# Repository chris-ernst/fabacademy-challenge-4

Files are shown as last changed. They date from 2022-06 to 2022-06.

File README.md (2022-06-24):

# Hybrid Ecosystems

## Building a bio-based MIDI controller for an interactive audiovisual performance

# SCOPE
Tati, Joaco and Chris are building a bio-based A/V interface. 

Basic structure:

1. Inputs (buttons) 
2. PCB
3. Outputs (Audio & Visuals)

In this documentation we will focus on the fabrication of the controller and the electronics as this was the main focus this week, but we will also touch upon wireless communication protocols. 

## [See our progress summary video on Vimeo](https://vimeo.com/717057704)

- [x] Initial idea / Concept of the Project ( What questions need to be answered?)

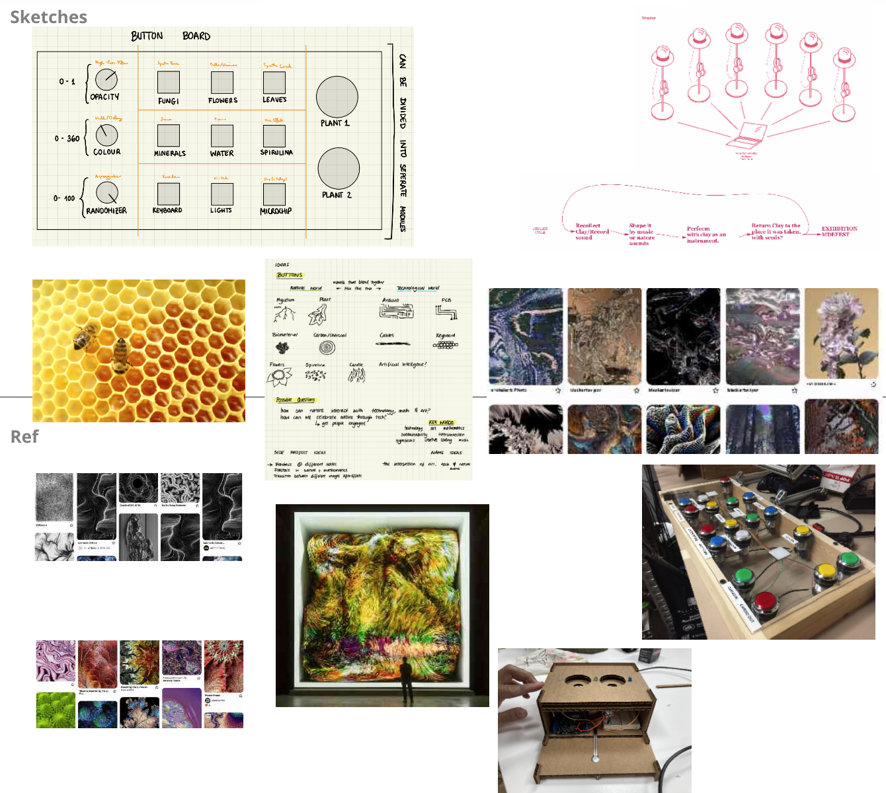
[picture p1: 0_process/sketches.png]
 

_How can we rethink a musical instrument? What are inputs, and how can they change shape and colors? How can we create engaging, collborative interactions with a button board?_

We wanted to make a modular button input system. After initially thinking about producing some sort of playable MIDI keyboard, we thought it could be interesting to incorporate two of Akasha hub's values into the design: decentralisation & sustainable relationships. So we designed the possibility for distributed buttons (which could be placed together with magnets or farther away) and rethought the buttons' materiality by using biomaterials.

We were inspired by the structure a visual aspect of beehives, which is why we ended up going for the hexagonic shape.

For the challenge we wanted to test out a diversity of inputs: we selected a "normal" clicking button, a potentiometer and a pressure sensor. This way, we could get a good understanding of each one and simply scale up the process based on our needs in the future.

- [x] Purpose: What is it supposed to do?

These buttons would then trigger visuals through Touchdesigner and audio through Ableton, at the same time, through TDAbleton protocols using wireless communication through IP addresses.

# ACADEMIC LEVEL

## Long term dissemination plan
explain the strategy you will use to share with future users your project (licences, tools, communication, etc)

Easy to scale up: we already have the 3D files for a button, potentiometer and pressure sensor, so it is only a matter of repeating the 3D printing.

As for the audiovisual files, Touchdesigner is free for personal use and has a very active community, so we could post the file on TD forums for people to use and learn. Ableton, on the other hand is very not open source and expensive, so it wouldn't be easy to share that with people who do not have a license for it.

- [x] Explain how it's linked to your research areas

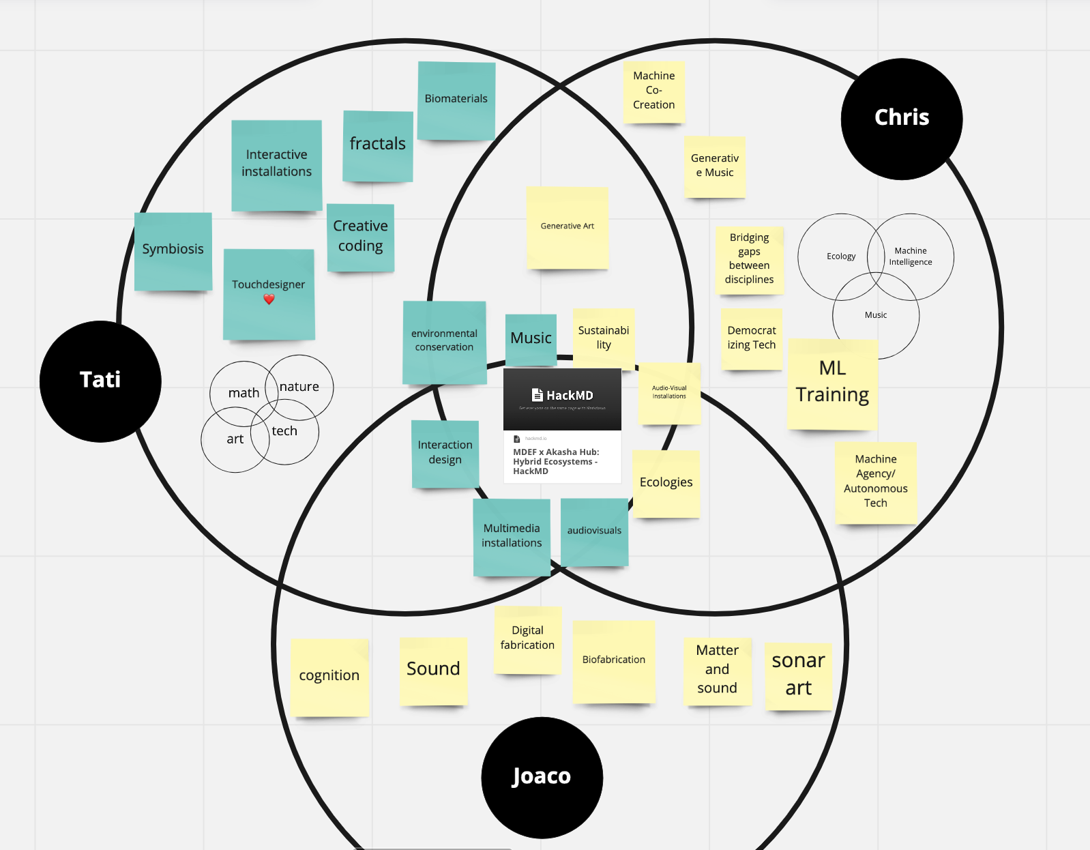
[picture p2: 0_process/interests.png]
 

Our research areas are very similar, even though we hav different focal points. The common areas are music, sustainability, environmental awareness, multimedia installations, interaction design, ecologies and audiovisuals. Our individual niches and specialties are 
  - Juaco: sound, digital fabrication, matter & sound, sonar art, biofabrication and cognition
  - Tatiana: interactive installations, creative coding, symbiotic relationships, fractals, biomaterials and the one and only Touchdesigner <3
  - Chris: ML training, Autonomous tech, democratising tech, bridging gaps between disciplines, generative music.

We've liked working together because we manage to each find a way to reach a common objective (Audiovisual VJ set with biomaterials) without compromising our specific interests (bio fabrication, creative coding, generative music etc.).

- [x] Show how your team planned and executed the project

We divided the group based on skills and interests: Juaco worked on the 3D printing, moulding & casting and soldering, Chris worked on the electronics, pcb milling and Ableton sountrack and Tatiana figured out how to structure the pipeline in Touchdesigner to receive, remap and send data through various protocols.
We often teamed up and helped each other out on various tasks but generally, we can say that our biggest tasks were digital fabrication, biomaterial moulding, PCB milling, electronics, wireless communications, audio & visuals generation.

- [x] System diagram (illustration explaining function, parts, and relations)

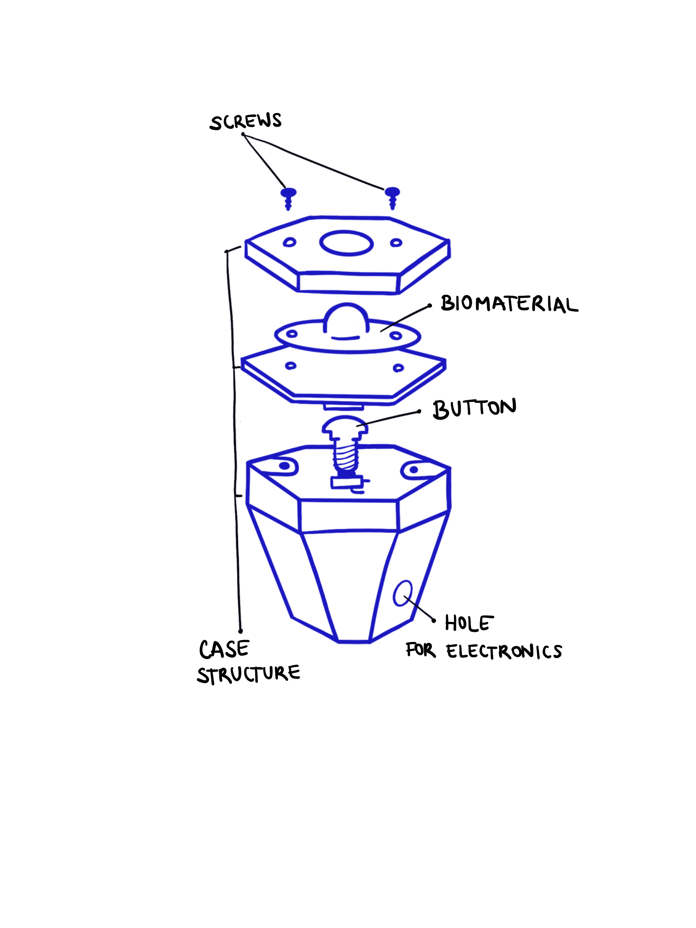
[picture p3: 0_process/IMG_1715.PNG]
 
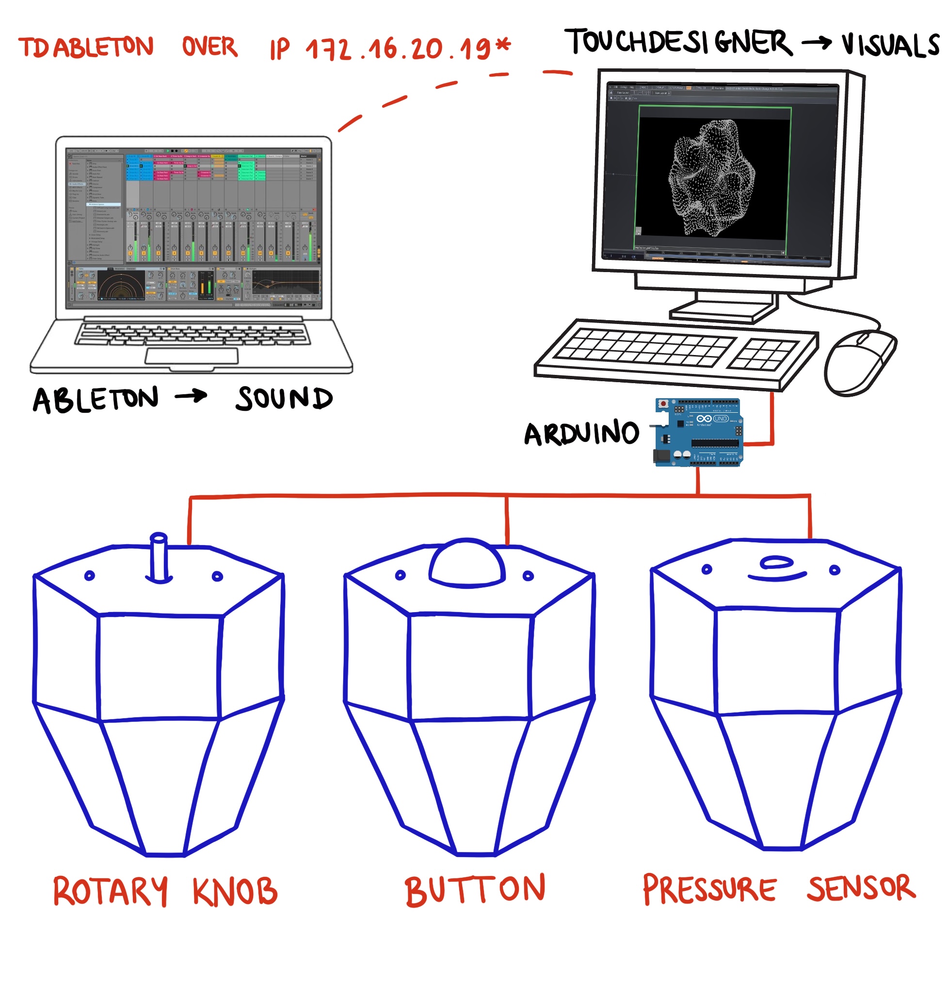
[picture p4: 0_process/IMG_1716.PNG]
 

All the buttons are connected to Arduino that is communicating the data to Touchdesigner. Each button triggers a visual + sound and each potentiomenter changes the color, shape and pitch.

- [x] BOM (Build of Materials)

Material used:

- 3 buttons
- 3 potentiometers
- 1 touch sensor
- biomaterials
- 3D materials for printing models for moulding and casting
- 3D materials for printing the box
- cables
- screws
- Arduino board

## Button board

This button board requires 3D modelling, molding and casting, electronics.

- [x] Integrated Design (How you designed it - relation between elements)

The input (button, rotor, pressure sensor) has a 3D printed case which keeps it stable and allows us to place it where we want. It is connected to the arduino (Code found in project files) which communicates the data into touchdesigner. This data is either binary, 0/1 for the button, or a range, like 0-1023 for the rotary knob. This data is remapped in Touchdesigner according to our needs: for example, 0-1023 is remapped to 1-360 in order for the rotary knob to change the hue of the colour selected in the visual. The buttons activate the visuals in Touchdesigner, but also simulatenously send midi values to ableton thanks to the TDAbleton link we set up for the two softwares to communicate.

- [x] Honest Design (use of technology in a meaningful way) Relation to the topics

We believe the technology was used in a meaningful way because we thought about how to conceptually match our vision with the experience. In other words, since we want participants to think about how technology, art and nature are connected in a collaborative way, we wanted this to be reflected in the button board itself, which is why we chose to make it decentralised with biomaterial and electronic components.

- [x] Be creative (find solutions with materials and technology you have)

We were creative in our approach and execution of the product, starting from the sketches, to the cardboard prototype and finally the product itself.

- [x] Explore design boundaries (based on your expertise)

We were unfamiliar with OSC and IP communication protocols, so this was an area we really had to push ourselves in, but it ended up being very beneficial.

- [x] Listed future development opportunity for this project

We want to scale up this project to 9 buttons, 3 rotary knobs and even plants, so that we can have a big, multi-person, interactive jamming board.

# REPLICABILITY

- [x] How did you fabricate it (fabrication processes and materials)

All of the files are inside the folder.

Juaco started out by prototyping the button cases in cardboard, and surely enough he whipped up a great prototype out of nowhere.

### 3D Fabrication

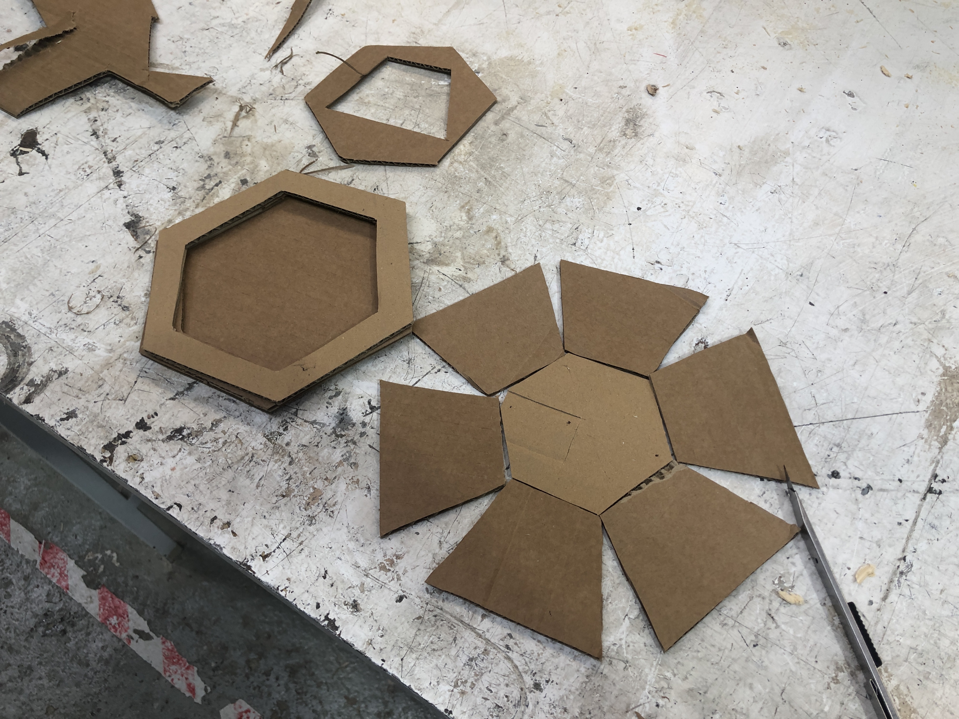
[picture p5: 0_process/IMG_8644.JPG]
 
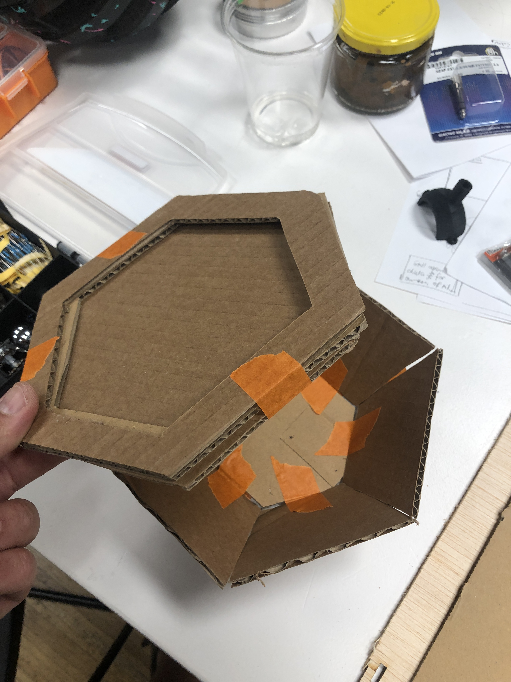
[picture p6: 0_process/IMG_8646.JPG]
 

Then, he designed the final structure to be 3D printed in Fusion 360, with slight tweaks for each type of input (based on the shape of the button/knob).

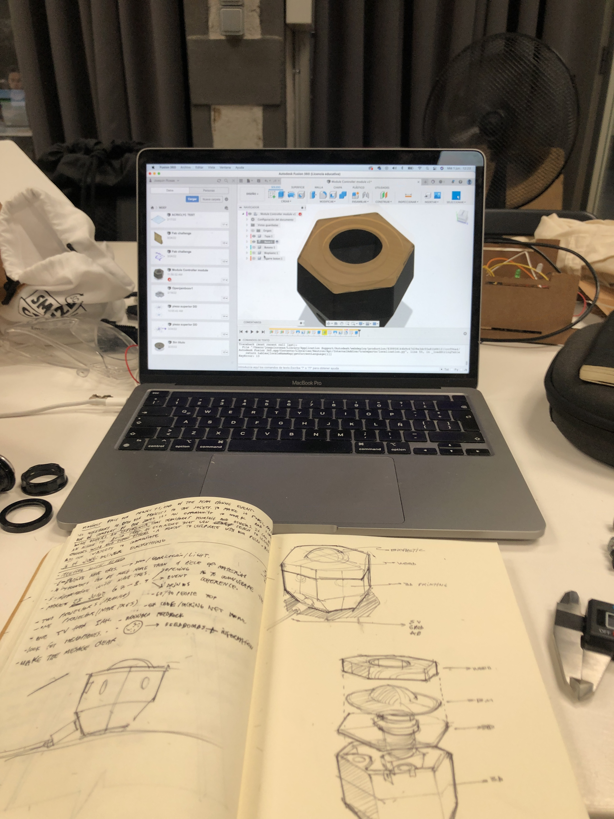
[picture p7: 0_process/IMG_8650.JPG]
 
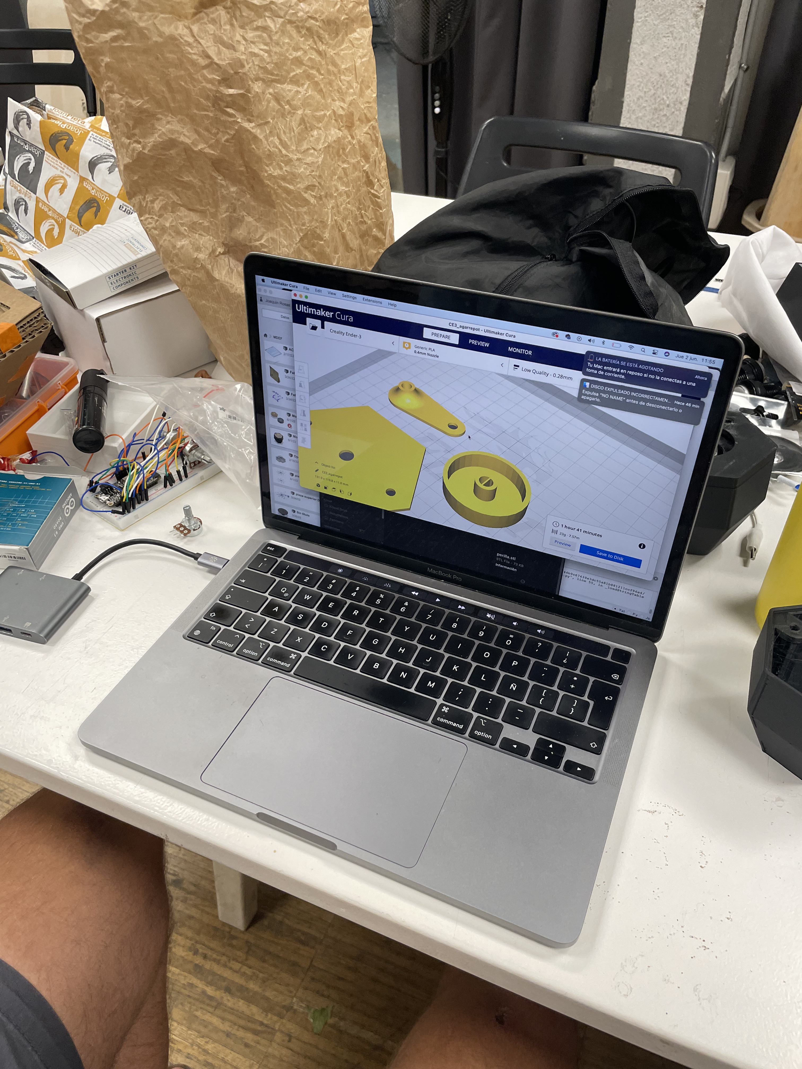
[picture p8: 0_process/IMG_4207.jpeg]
 

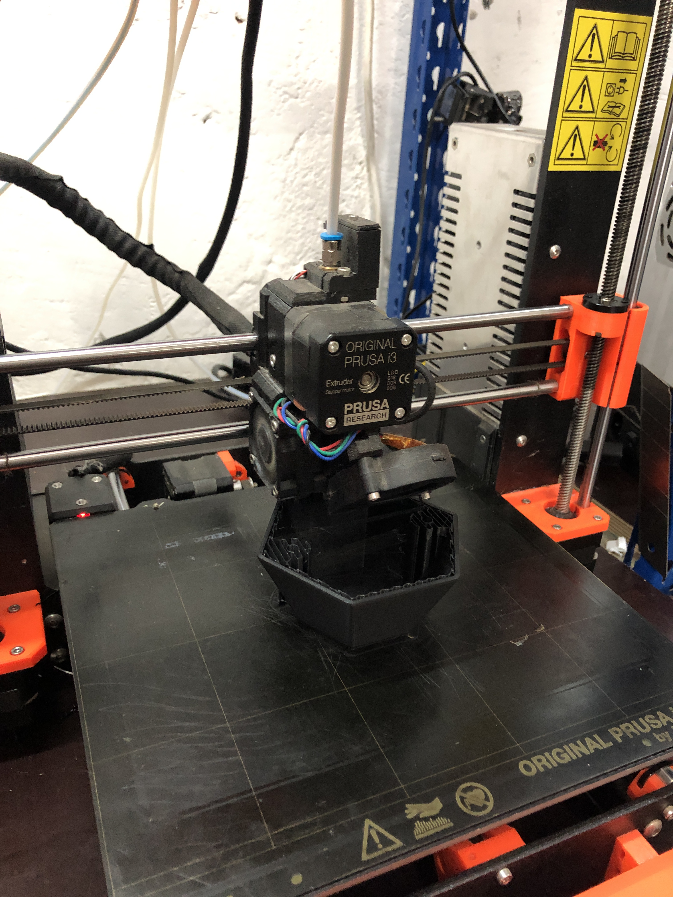
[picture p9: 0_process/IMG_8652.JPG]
 
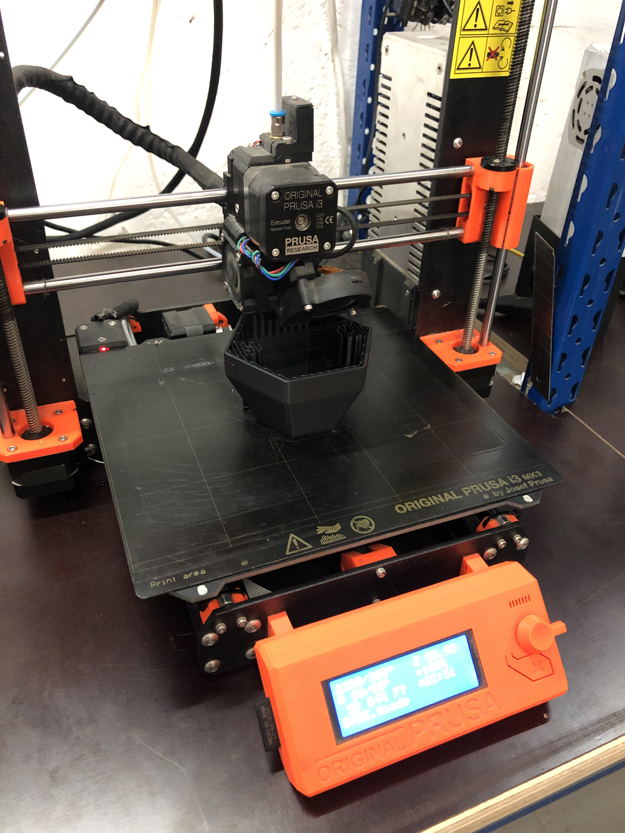
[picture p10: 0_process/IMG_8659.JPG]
 

### Molding & Casting

Recipe for biomaterials can be found [here](/2_biomaterials).

Juaco also designed the mould for the biomaterials, so that it could fit perfectly into the case.

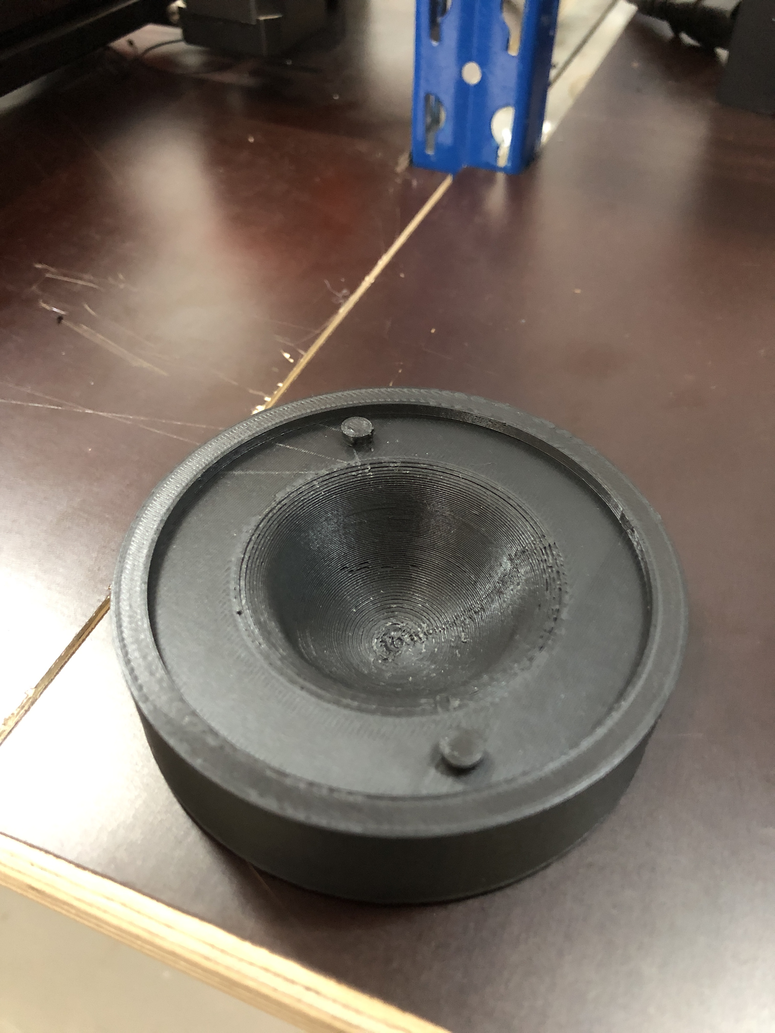
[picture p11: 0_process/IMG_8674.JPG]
 
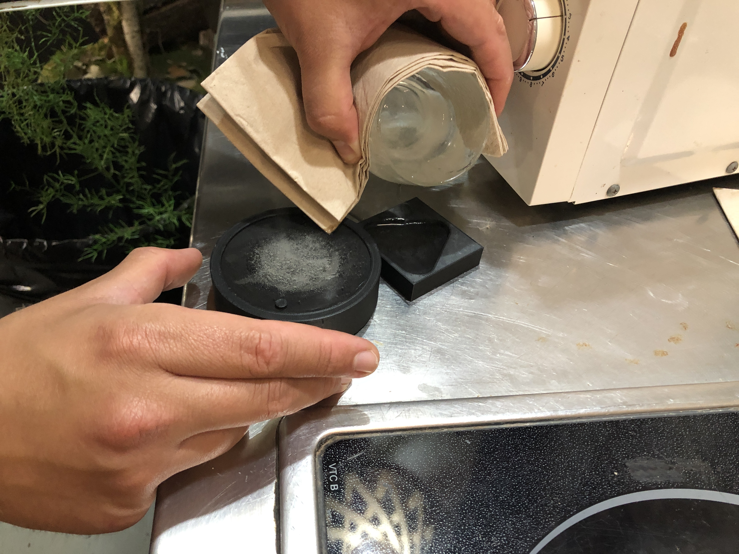
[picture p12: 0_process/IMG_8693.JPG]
 
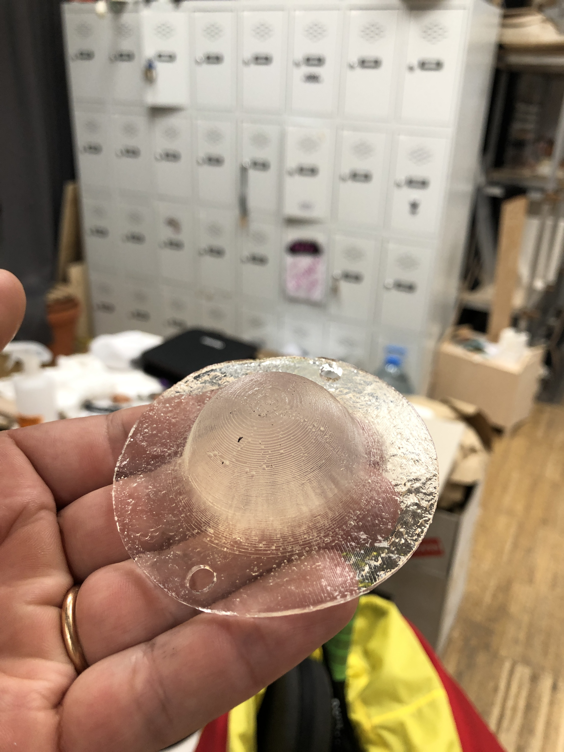
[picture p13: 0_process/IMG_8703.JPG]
 

### Milling and Soldering an Arduino Shield

Chris was responsible for designing, milling and soldering a Arduino Shield to multiply the GND and 5V outputs for the controller. 

Some notes on fabrication
- Trace mill: min. 1/64"
- Outline mill: 1/32"
- Trace seperation: 2.55mm
- Minimal trace width: 0.35mm 
- Trace clearance: 0.4mm
- Hole diameter: 1mm

PCB files can be found [here](/1_fabrication/Arduino_Shield).

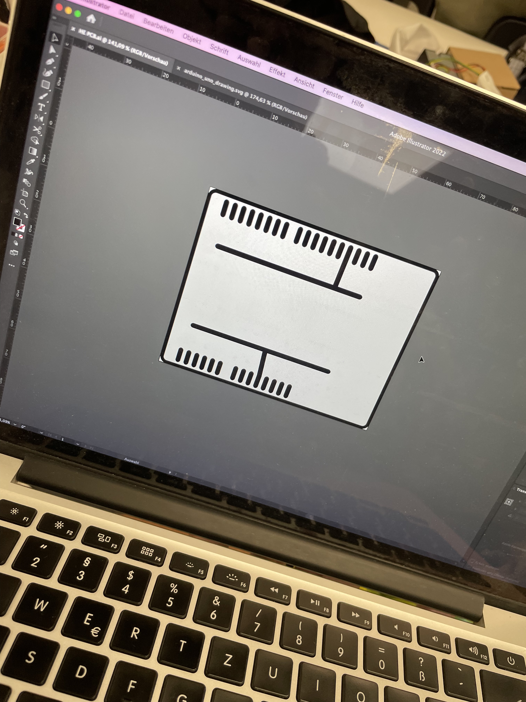
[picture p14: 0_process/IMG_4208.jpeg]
 
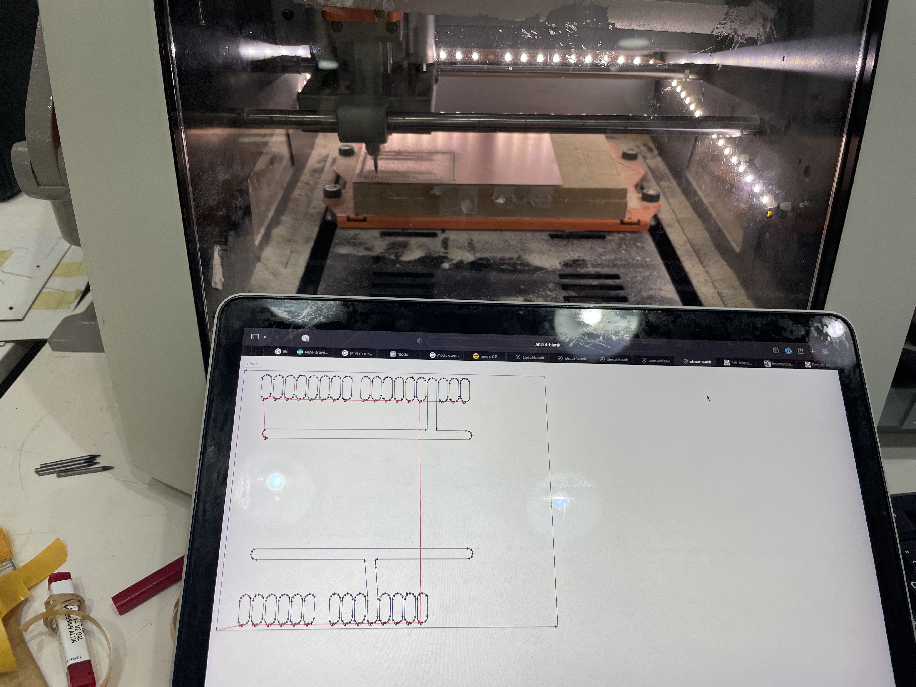
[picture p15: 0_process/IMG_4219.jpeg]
 
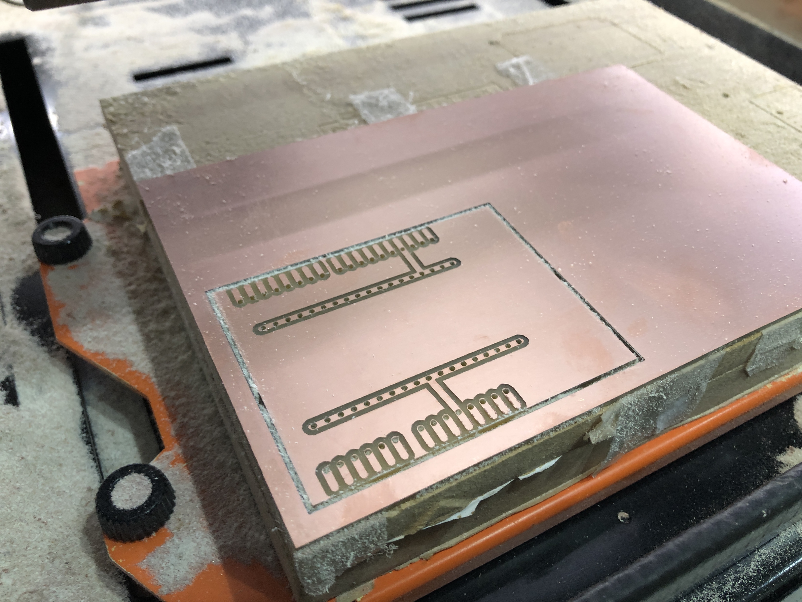
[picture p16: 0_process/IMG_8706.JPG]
 
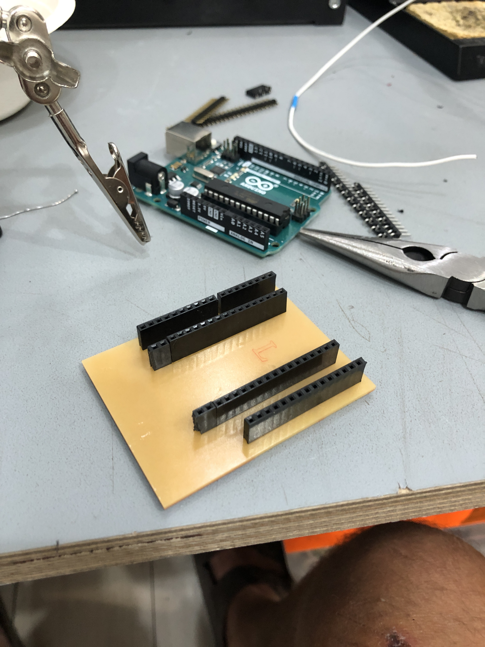
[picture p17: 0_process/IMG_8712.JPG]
 
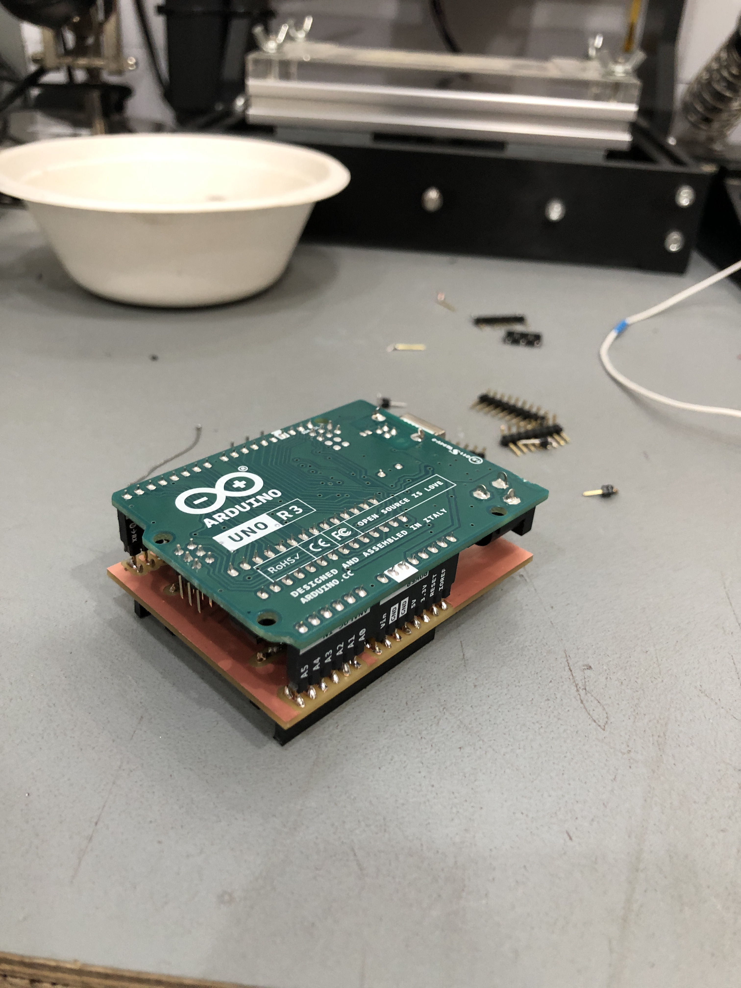
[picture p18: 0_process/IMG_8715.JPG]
 

## Audiovisuals

Tatiana coordinated the audiovisuals and managed the incoming and outgoing data

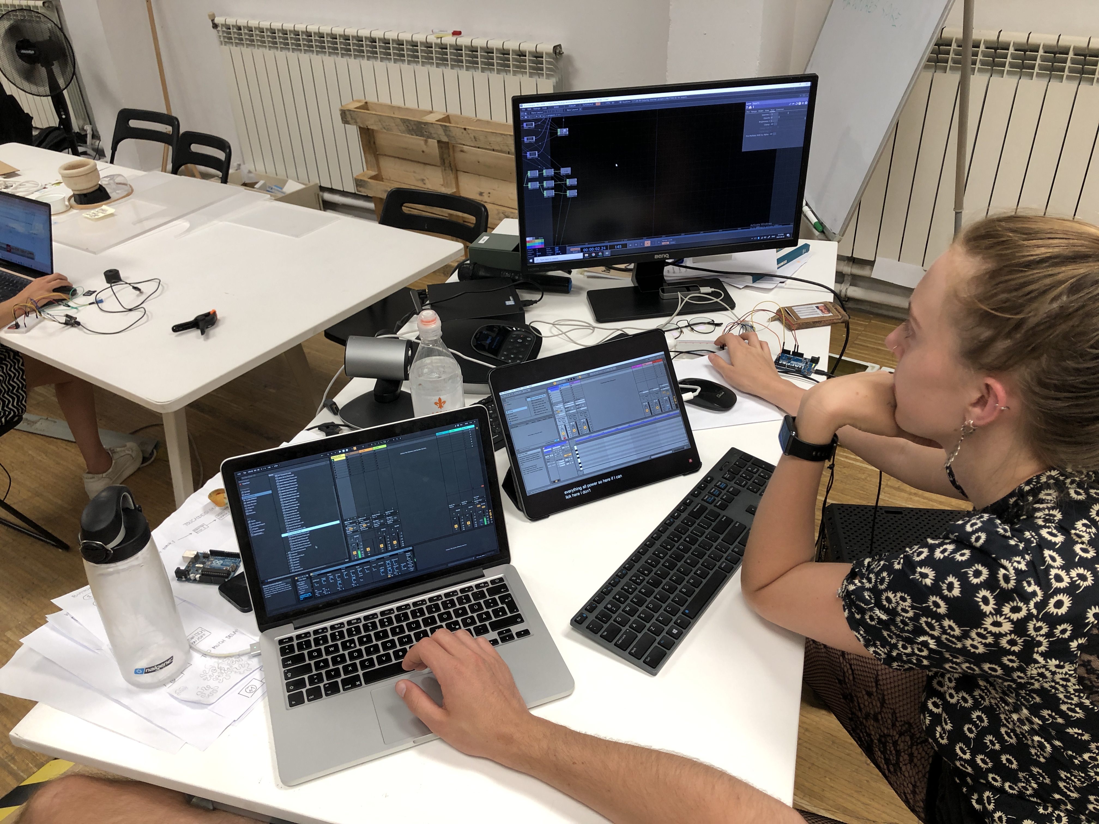
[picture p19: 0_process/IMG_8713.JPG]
 
 

Together, we worked on the electronics, iterating based on our testing needs. We started out with a simple button and then proceeded to add knobs and pressure sensors. Chris and Tatiana worked on the arduino code and how to visualise it in Touchdesigner.

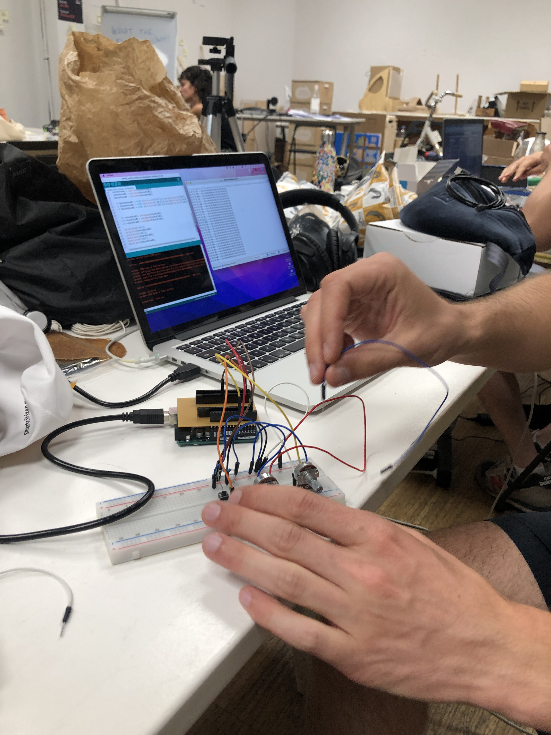
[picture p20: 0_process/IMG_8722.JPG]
 

- [x] Iteration Process (spiral development)

For the input cases

Cardboard prototype -> breadboard electronics -> 3D printed casing -> button biomaterial moulding 

For the audiovisual pipeline

1. Understanding OSC protocols with TouchOSC app communicating with Touchdesigner (just to get familiar with IP addresses and ports)
2. Receiving data from Arduino by using Serial DAT (operator node which receives serial data)
3. Communicating interchangeably between Touchdeisgner and Ableton, using TDAbleton over IP address

In both cases, we scaled up the difficulty over time, once we understood the basics of the software or technique.

- [x] Described problems and how the team solved them

As always, we had many bugs in the code, within the protocols and we often had to 

Out of all challenges, however, this was the one where we faced the least difficulties because we were so prepared and determined to getting things done, but also because we distributed our skills well and evenly without experimenting too much. It's always important to balance the experimenting enough to be out-of-the-box, yet be rigorous with time and organisation in order to finish within the deadlines.

- [x] Photographies of the end artifacts

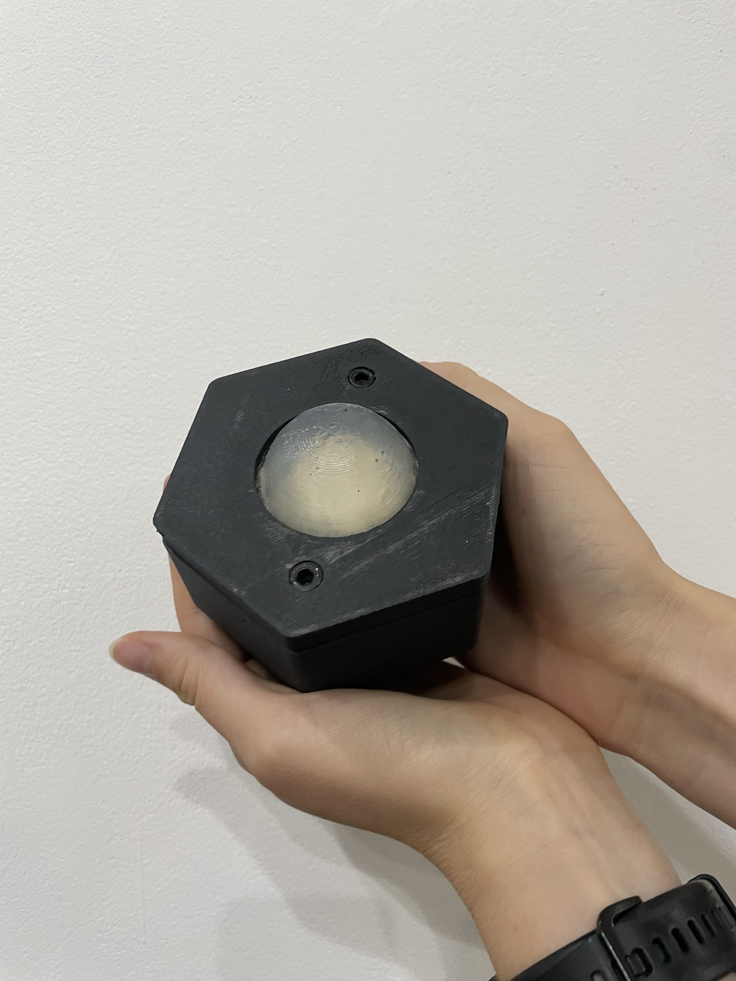
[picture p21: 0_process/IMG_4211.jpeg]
 

You can find the final process video [here](https://vimeo.com/717057704)

- [x] Dealing with uncertainty + Don't be afraid to make mistakes

The IAAC wifi sucks. Especially when there are dozens of students git pushing and uploading last minute files onto the repo. We were actually really disappointed with our final presentation because we were looking forward to showcasing our week of hard work to the class and professors, but the wifi bandwidth was not stable enough to maintain a connection between Tatiana and Chris' computer, which meant that Touchdesigner and Ableton were not able to communicate.

This is something to keep in mind for the final show, but maybe it was a way of us not "spoiling" the magic of the event.

## UPDATES !! <3

- [x] Explore design boundaries (based on your expertice)

We were unfamiliar with OSC and IP communication protocols, so this was an area we really had to push ourselves in, but it ended up being very beneficial to us. By doing this, we could then make Tatiana + Chris' computers communicate wirelessly, using two totally different programs through the magic powers of WIFI.

In addition to this, we believe our design was unique due to its modular button system. After initially thinking about producing some sort of playable MIDI keyboard in the shape of a box or drum pad, we thought it could be more interesting to make the components detachable and independant.

Juaco and Chris had explored making a loop station in the past, so choosing to sticking to that type of instrument would have been repetitive and solvable by already existing products (VJ button board, drum kits, keyboards...). However, by making the buttons in seperate components, we make our output unique and each show could be different. For example, we could have one show with the buttons all together in a beehive shape, and another where they are far apart. 

The distributed buttons' materiality is also innovative because of the use of biomaterials rather than silicone or plastic. This adds an interesting tactility when playing the buttons which is unlike other instruments. We would like to play around with the biomaterial textures and colours in the future.

- [x] Long term dissemination plan

The FabChallenge was a way for us to test out the technical side of our final exhibition. After coming up with the idea to have a DJ set at Akasha hub with various buttons to trigger the visuals, we wanted to make this possible with the skills we acquired over the course of  Fabacademy. The challenge allowed us to test various button possibilities and see which one was most suitable to be scaled up at the Akasha event, but also future events. 

We believe that the parametric design makes it easy to scale up: we already have the 3D files for our key elements, the button, potentiometer and pressure sensor, so it is only a matter of repeating the 3D printing to scale up the equipment. If we want to make slight modifications to the design it would be possible too, changing the parametric attributes on Fusion.

As for the audiovisual files, Touchdesigner is free for personal use and has a very active community, so we could post the file on TD forums for people to use and learn. Ableton, on the other hand is very not open source and expensive, so it wouldn't be easy to share that with people who do not have a license for it. This is what regards the dissemination of the project files.

When it comes to scaling up the actual experience beyond MDEF and Akasha hub, we have been discussing a few ideas. We think it would be very interesting to submit the project to certain design festivals, such as ARS Electronica or the Dutch Design week. This will all depend on the outcome of the Akasha event, and whether it is a success or not. If this would happen and we needed more artifacts, it would be easier to scale up for the reasons mentioned before: 3D printing the structure and replicating it. 

Ultimately, this is why we chose having a distributed button system, rather than a simple board. If we had a board, it wouldn't have been as flexible as the various buttons which can be produced and added on demand.

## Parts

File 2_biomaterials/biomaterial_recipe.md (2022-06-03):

# Biomaterial Recipe:

Agar Agar :4g

Water: 80 ml

Glycerin: 15 ml

Process: Mix everything togueter while its cold, then pour the mix on a glass, and heat it in a microwave for 1.30 min.

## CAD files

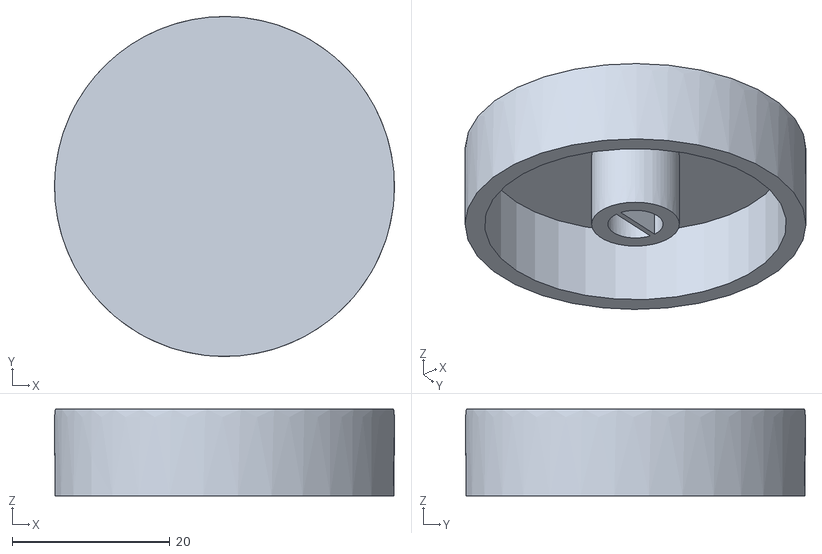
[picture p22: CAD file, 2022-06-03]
1_fabrication/STL files/perilla.stl
43.1 x 43.1 x 11.0

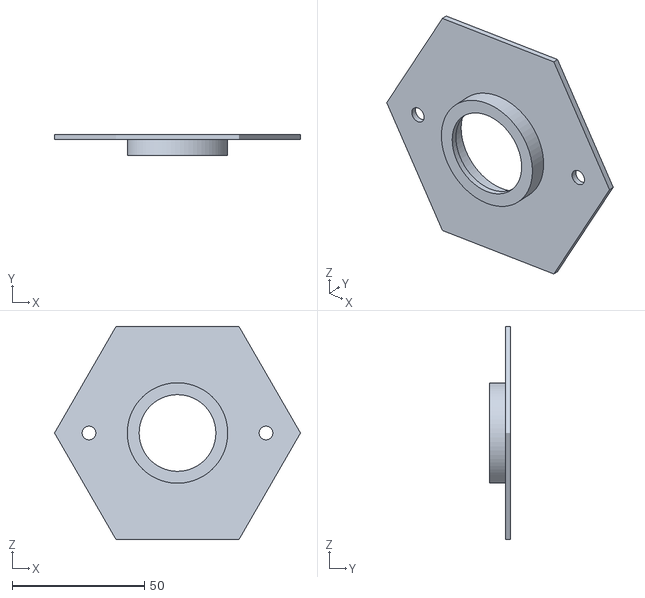
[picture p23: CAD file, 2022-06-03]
1_fabrication/STL files/button holder.stl
93.1 x 8.00 x 80.6

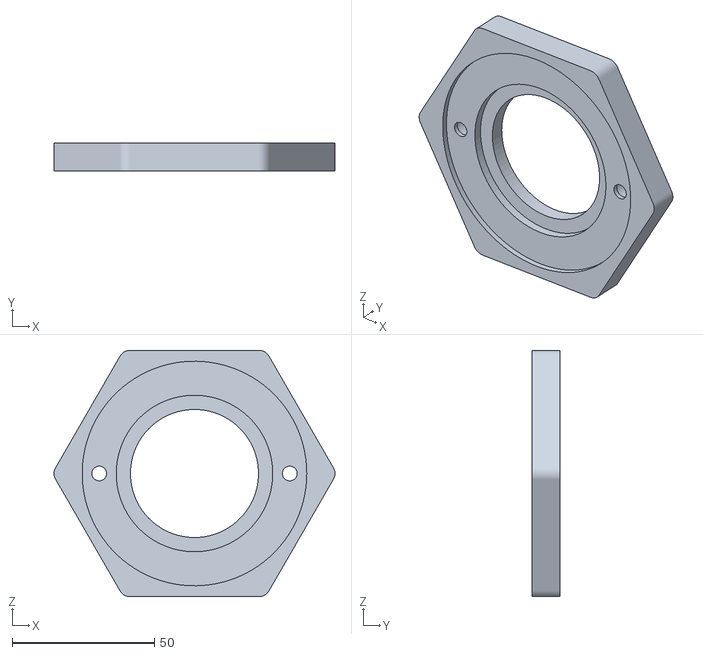
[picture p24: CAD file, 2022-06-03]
1_fabrication/STL files/button lid.stl
98.8 x 10.0 x 86.6

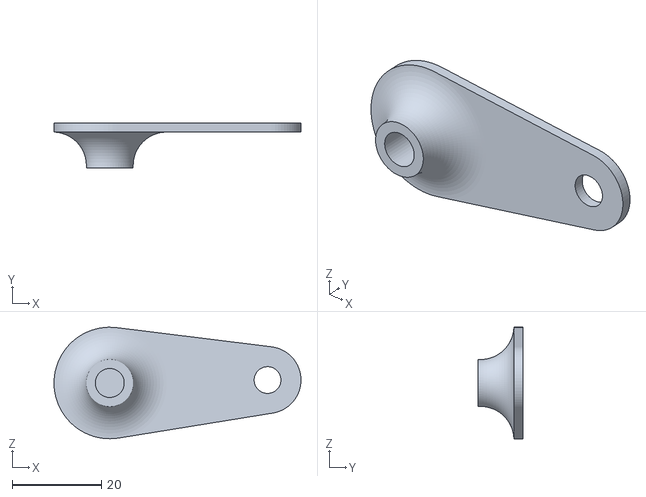
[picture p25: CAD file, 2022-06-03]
1_fabrication/STL files/lever.stl
55.3 x 10.0 x 25.0

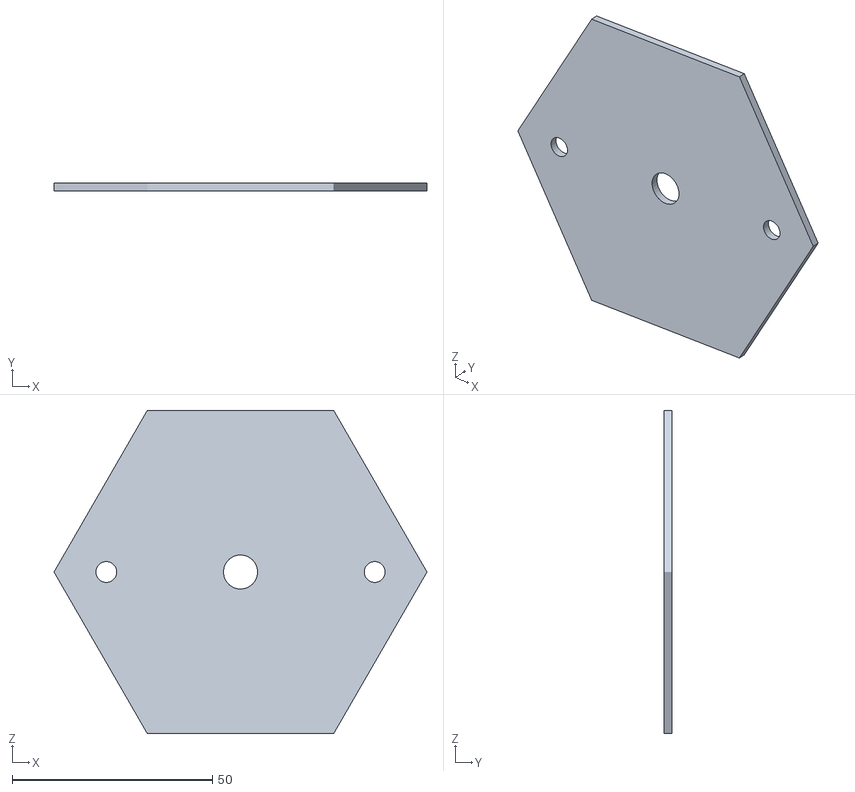
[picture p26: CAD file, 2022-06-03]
1_fabrication/STL files/Potentiometer holder.stl
93.1 x 2.00 x 80.6

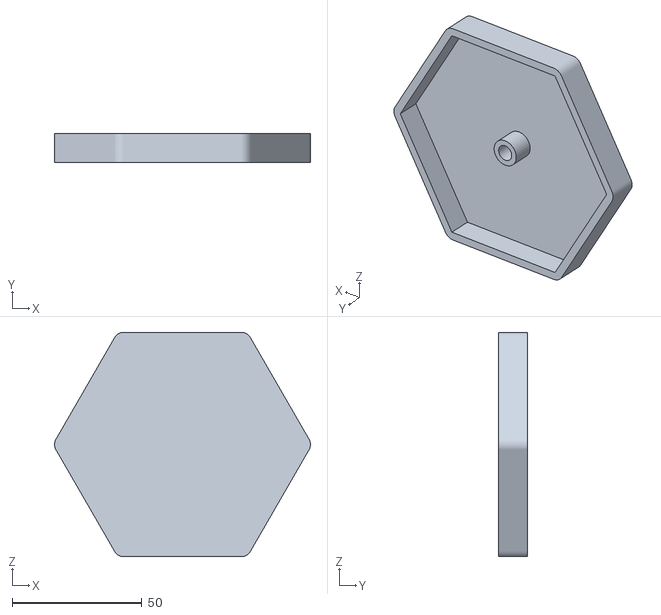
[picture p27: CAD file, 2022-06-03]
1_fabrication/STL files/pot lid.stl
98.8 x 11.0 x 86.6

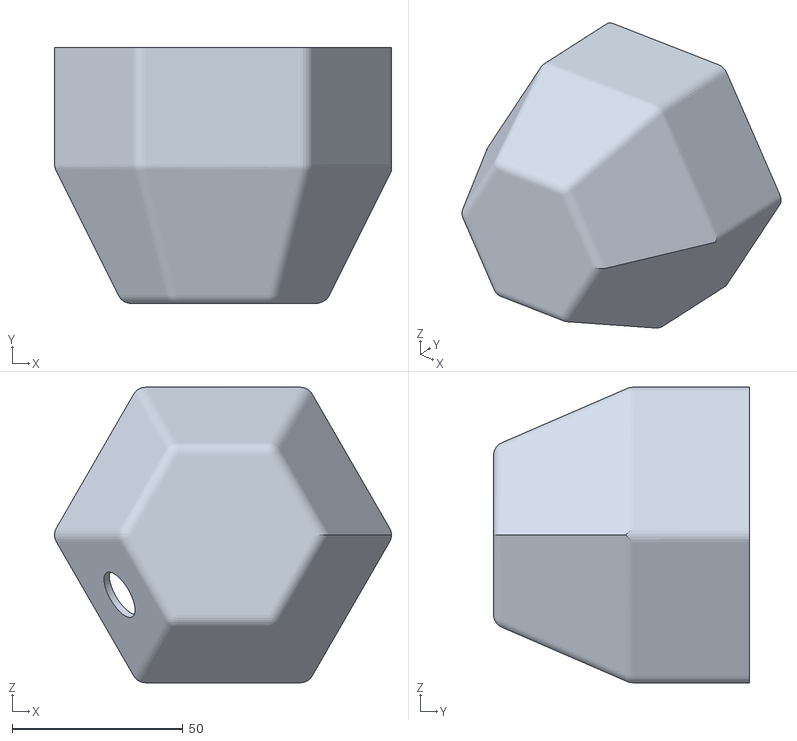
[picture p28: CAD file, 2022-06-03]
1_fabrication/STL files/BASE.stl
98.7 x 75.0 x 86.6

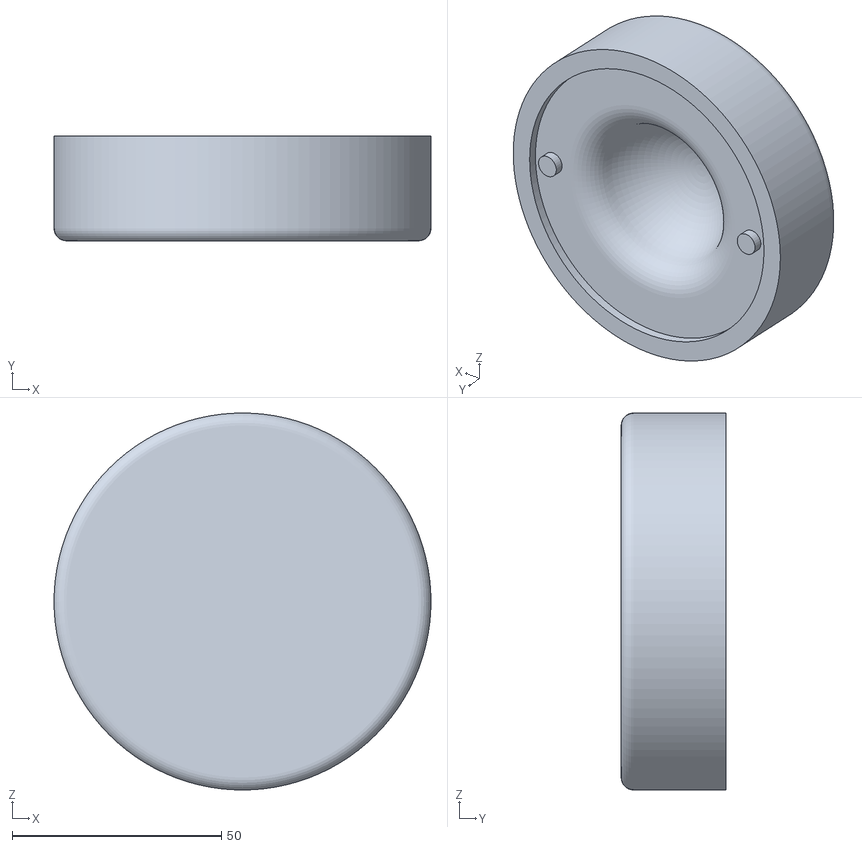
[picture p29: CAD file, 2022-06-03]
1_fabrication/STL files/mold.stl
90.0 x 25.0 x 90.0

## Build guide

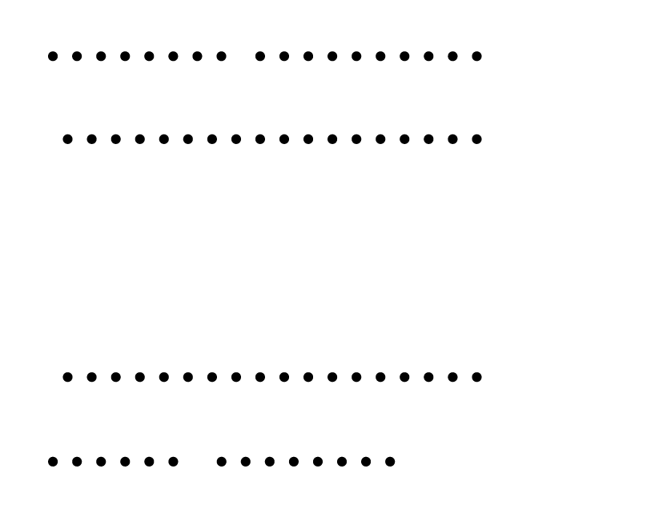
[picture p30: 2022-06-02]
1_fabrication/Arduino_Shield/PNG Files/HE PCB_holes.png

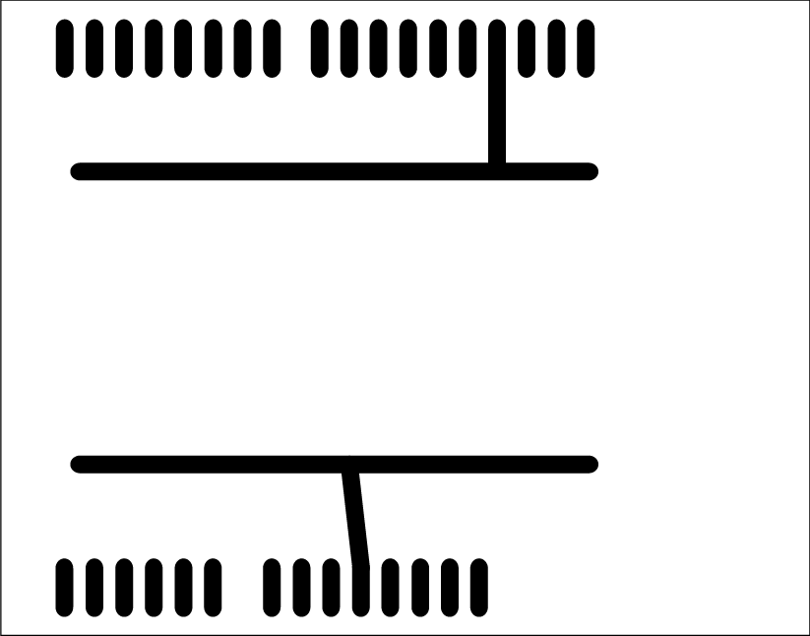
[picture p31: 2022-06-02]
1_fabrication/Arduino_Shield/PNG Files/HE PCB_traces.png

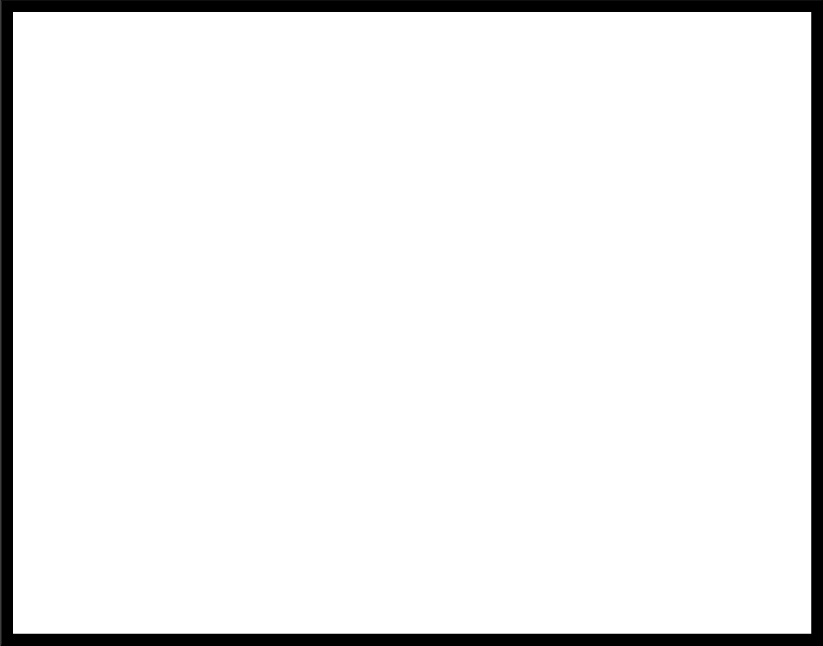
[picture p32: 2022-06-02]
1_fabrication/Arduino_Shield/PNG Files/HE PCB_outline.png

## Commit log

2022-06-02 Updated with PCB files and notes
2022-06-03 Updated PCB documentation
